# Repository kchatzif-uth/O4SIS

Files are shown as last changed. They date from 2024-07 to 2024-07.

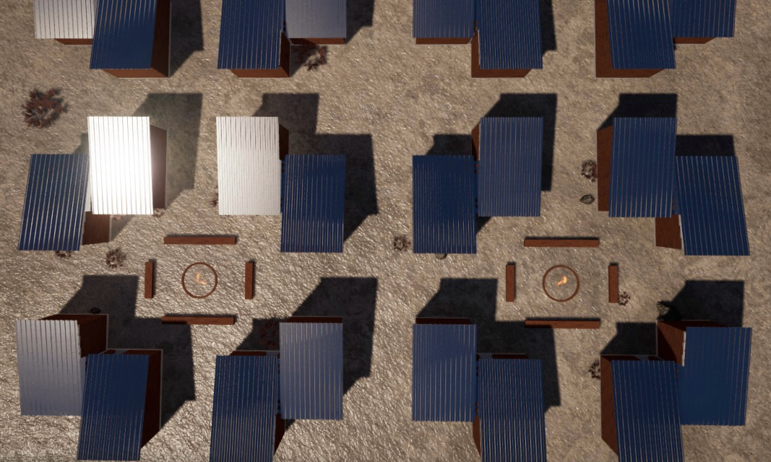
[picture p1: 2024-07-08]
ΦΩΤΟΡΕΑΛΙΣΤΙΚΑ/4.png

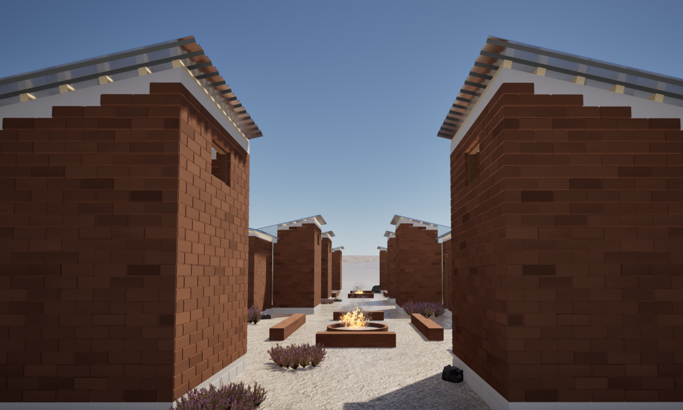
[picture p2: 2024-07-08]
ΦΩΤΟΡΕΑΛΙΣΤΙΚΑ/3.png

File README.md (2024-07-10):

Είμαστε μια ομάδα φοιτητριών του Πανεπιστήμιου Θεσσαλίας στο τμήμα Αρχιτεκτόνων Μηχανικών. Στο πλαίσιο του διδακτικού μαθήματος Ανοιχτός σχεδιασμός, κατασκευή και τεχνολογίες σχεδιάσαμε ένα πρωτότυπο καταφύγιο για πρόσφυγες. Η περιοχή εγκατάστασης του προτεινομένου καταυλισμού είναι η Υποσαχάρια Αφρική (Σαχέλ), συγκεκριμένα το Um Rakuba, Doka, του Σουδάν. Πρόκειται για μια μονάδα 20.75 τ.μ. ελάχιστης κατοίκισης, η οποία μπορεί να φιλοξενήσει έως 6 άτομα σε ανάγκη παρέχοντας 3.45τμ/άτομο. Το σχήμα της μονάδας αποτελείται από δυο παραλληλόγραμμα ίσου μεγέθους με κεκλιμένες οροφές αντίθετης κλίσης. Τα παραλληλόγραμμα απέχουν μεταξύ τους 0.2m και ενώνονται με 4 στήλες τούβλων και ένα ειδικό τεμάχιο. Το ένα τμήμα στεγάζει τον χώρο διαμονής με το υπνοδωμάτιο παρέχοντας τρείς κουκέτες ενώ το άλλο, τον χώρο διημέρευσης που αποτελείται από το μπάνιο και την κουζίνα. Το σχήμα έχει τέτοια δομή έτσι ώστε να πολλαπλασιάζεται σε 4αδες και να δημιουργούνται ανάμεσα χώροι συγκέντρωσης και συνάθροισης. Οι χώροι αυτοί λειτουργούν ως πλατείες, που στο κέντρο τους τοποθετείτε μία εστία που εξυπηρετεί στο μαγείρεμα και περιμετρικά υπάρχουν παγκάκια. Σκοπός, είναι η κατασκευή να ανταποκρίνεται στα κλιματολογικά και γεωγραφικά δεδομένα της επιλεγμένης περιοχής και η χρήση τοπικών υλικών. Έτσι με βάση μελέτης της περιοχής που επιλέχθηκε για την τοποθέτηση των καταλυμάτων, το Σουδάν, το μεγαλύτερο ποσοστό που αποτελεί τη μονάδα, τα τούβλα, παράγονται με χώμα, φλούδες ρυζιού και νερό. Κατά κύριο λόγω, η κατασκευή είναι ‘ανοιχτή’ τόσο σε σχεδιασμό όσο και σε κατασκευαστικό τομέα, καθώς όλα τα σχετικά δεδομένα που απαιτούνται για την δόμηση του καταλύματος βρίσκονται διαθέσιμα στην πλατφόρμα GITHUB. Τα δεδομένα αυτά προορίζονται για εθελοντές, οι οποίοι θα αναλάβουν πραγματοποίηση των καταφυγίων, στους οποίους θα απευθυνθούμε μέσω της της οργάνωσης UNHCR.

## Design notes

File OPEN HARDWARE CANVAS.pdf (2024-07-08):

ΤΟΥΒΛΑ x1804 (0,2m x 0,4m x 0,15m) ΛΑΜΑΡΙΝΕΣ x2 (3,2m x 4,7m) ΤΣΙΜΕΝΤΟΛΙΘΟΥΣ x62 (0,2m x 0,4m x 0,25m) ΞΥΛΙΝΑ ΔΟΚΑΡΙΑ x18 (0,1m x 0,1m x 2,9m) ΕΙΔΙΚΟ ΤΕΜΑΧΙΟ x1
ΥΔΡΟΡΡΟΕΣ x2 (d: 0,12m y: 3m)
ΞΥΛΙΝΕΣ ΚΑΣΕΣ ΠΑΡΑΘΥΡΟΥ x2 (0,8m x 0,6m x 0,1m)
ΞΥΛΙΝΗ ΚΑΣΑ ΠΟΡΤΑΣ x1 (0,8m x 2,25m x 0,1m) ΕΙΔΙΚΗ ΒΑΣΗ ΞΥΛΟΥ x36

Τοποθεσία:Um Rakuba, Doka, Σουδάν (ΣΑΧΕΛ) 20.75 m2 (3.45m2 / άτομο)
Καταφύγιο

Πρόσφυγες των γύρω περιοχών της Um Rakuba, Doka

.dwg (AUTOCAD)
.3dm (RHINO)
.pdf
.doc
.pptx
.mp4
.md

SOFTWARE:
Github
Autodesk

Υπολογιστής
Ίντερνετ
Υλικά -Εξοπλισμός κατασκευής: ΦΥΛΛΑΔΙΟ 01 (Github)
Open Design, Structures & Technologies | ΘΩΜΑ, ΧΑΤΖΗΦΩΤΙΑΔΟΥ, ΧΡΙΣΤΟΦΙΛΟΥ
- https://www.researchgate.net/figure/Spacers-used-to-preventcompressing-the-insulation_fig5_348600514 (https://www.researchgate.net/figure/Spacers-used-to-prevent-compressing-the-insulation_fig5_348600514)
- https://www.dezeen.com/2019/09/17/cortex-shelter-cutworkrefugee-architecture/ (https://www.dezeen.com/2019/09/17/cortex-shelter-cutwork-refugee-architecture/)
- https://www.designboom.com/architecture/shigeru-ban-kalobeyeirefugee-shelters-turkana-kenya-philippe-monteil-un-habitat-unhcr-03-07-2022/ (https://www.designboom.com/architecture/shigeru-ban-kalobeyei-refugee-shelters-turkana-kenya-philippe-monteil-un-habitat-unhcr-03-07-2022/)
- https://perunanuovacasaitaliana.wordpress.com/2016/04/15/architects-for-society-designs-low-cost-hexagonal-shelters-for-refugees/ (https://perunanuovacasaitaliana.wordpress.com/2016/04/15/architects-for-society-designs-low-cost-hexagonal-shelters-for-refugees/)

Ομάδα εθελοντών με εξοικείωση στον κατασκευαστικό τομέα

Θα συνεργαστούμε με την οργάνωση UNHCR μέσω της οποίας θα βρεθεί η κατάλληλη ομάδα εθελοντών για την κατασκευή του καταυλισμού

# O 4 S I S

Οδηγίες (Github):
1. ΦΥΛΛΑΔΙΟ 01: https://github.com/kchatzifuth/O4SIS/blob/main/%CE%A6%CE%A5%CE%9B%CE %9B%CE%91%CE%94%CE%99%CE%9F%2001.pdf
2. ΦΥΛΛΑΔΙΟ 02: https://github.com/kchatzifuth/O4SIS/blob/main/%CE%A6%CE%A5%CE%9B%CE %9B%CE%91%CE%94%CE%99%CE%9F%2002.pdf

Θα απευθυνθούμε στηνοργάνωση UNHCR μέσω της οποίας θα βρεθούν τα άτομα σε ανάγκη

Δεν χρειάζεται κάποιο είδος οδηγίας προκυμμένου να χρησιμοποιηθεί η συγκεκριμένη δομή.

Software:
- AUTOCAD
- ADOBE SYSTEMS

Οδηγίες στο Github:
- ΦΥΛΛΑΔΙΟ 01
- ΦΥΛΛΑΔΙΟ 02
- GIF

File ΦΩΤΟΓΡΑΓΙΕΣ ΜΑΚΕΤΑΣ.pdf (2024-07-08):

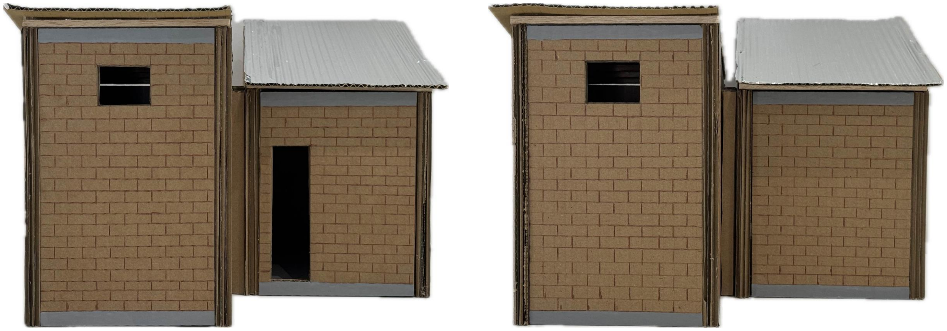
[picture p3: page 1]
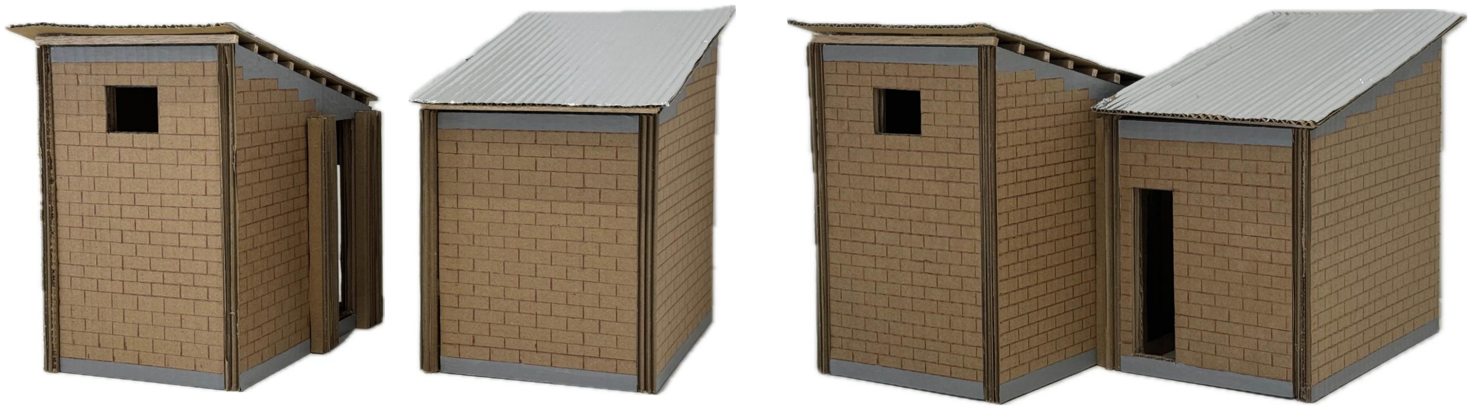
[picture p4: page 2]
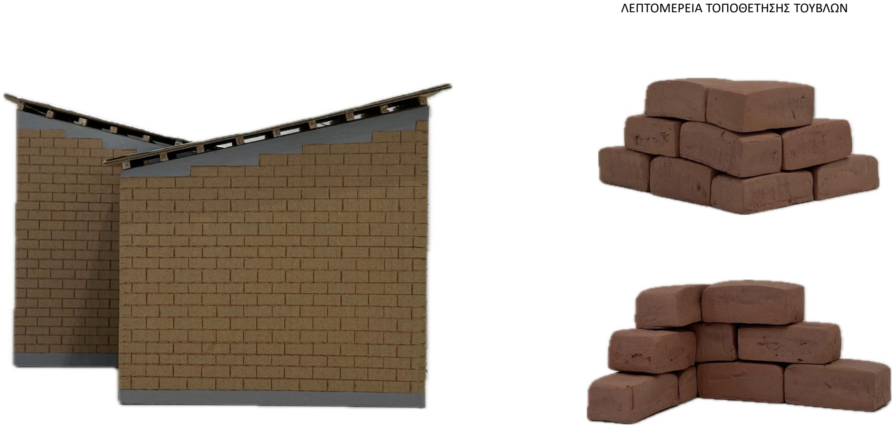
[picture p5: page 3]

ΛΕΠΤΟΜΕΡΕΙΑ ΤΟΠΟΘΕΤΗΣΗΣ ΤΟΥΒΛΩΝ

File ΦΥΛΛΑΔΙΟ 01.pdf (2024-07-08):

### ΦΥΛΛΑΔΙΟ 01: ΟΔΗΓΙΕΣ ΚΑΤΑΣΚΕΥΗΣ

ΥΛΙΚΑ

ΕΞΟΠΛΙΣΜΟΣ

ΤΟΥΒΛΑ x1804 (0,2m x 0,4m x 0,15m) ΛΑΜΑΡΙΝΕΣ x2 (3,2m x 4,7m) ΤΣΙΜΕΝΤΟΛΙΘΟΥΣ x62 (0,2m x 0,4m x 0,25m) ΞΥΛΙΝΑ ΔΟΚΑΡΙΑ x18 (0,1m x 0,1m x 2,9m)
ΕΙΔΙΚΟ ΤΕΜΑΧΙΟ x1
ΥΔΡΟΡΡΟΕΣ x2 (d: 0,12m y: 3m)
ΞΥΛΙΝΕΣ ΚΑΣΕΣ ΠΑΡΑΘΥΡΟΥ x2 (0,8m x 0,6m x 0,1m) ΞΥΛΙΝΗ ΚΑΣΑ ΠΟΡΤΑΣ x1 (0,8m x 2,25m x 0,1m) ΕΙΔΙΚΗ ΒΑΣΗ ΞΥΛΟΥ x36
ΒΙΔΕΣ ΞΥΛΟΥ x216
ΒΙΔΕΣ ΓΙΑ ΛΑΜΑΡΙΝΑ x36
ΕΠΙΚΑΛΥΠΤΡΑ x36
ΜΠΕΤΟ

ΚΑΛΟΥΠΙ ΤΟΥΒΛΩΝ
ΜΕΤΡΟ
ΦΤΥΑΡΙ
ΚΡΟΥΣΤΙΚΟ ΤΡΥΠΑΝΙ
ΓΑΝΤΙΑ
ΚΑΤΣΑΒΙΔΙ
ΓΑΛΛΙΚΟ ΚΛΕΙΔΙ

Βήμα 1:
Συγκεντρώνουμε τα υλικά (χώμα, νερό, φλούδες ρυζιού).
Αναμειγνύουμε το χώμα με το νερό και έπειτα προσθέτουμε τις φλούδες ρυζιού έως ότου να ομογενοποιηθούν.

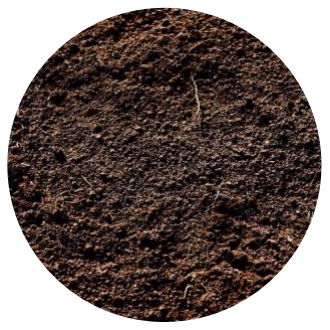
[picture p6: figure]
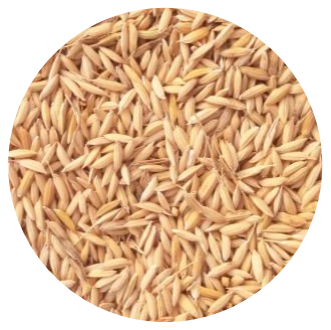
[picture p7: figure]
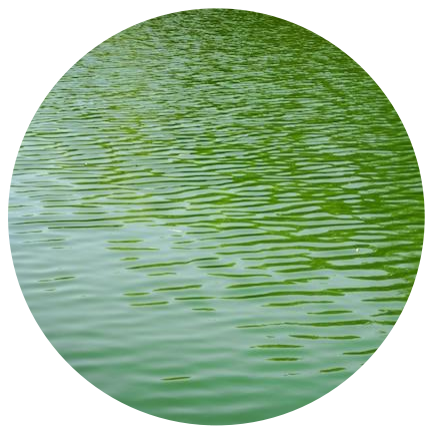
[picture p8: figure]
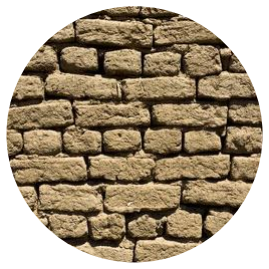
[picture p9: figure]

Εικ.1. Χώμα | Εικ.2. Φλούδες ρυζιού | Εικ.3. Νερό | Εικ.4. Τούβλα Λάσπης

Βήμα 2:
Γεμίζουμε το κάθε καλούπι με το χώμα, το ξεφορμάρουμε και το αφήνουμε στον ήλιο για 10 μέρες για να σταθεροποιηθούν. Σχηματίζουμε τούβλα 20x40x15 cm. Επαναλαμβάνουμε την ιδιά διαδικασία για όσες φορές χρειαστεί.

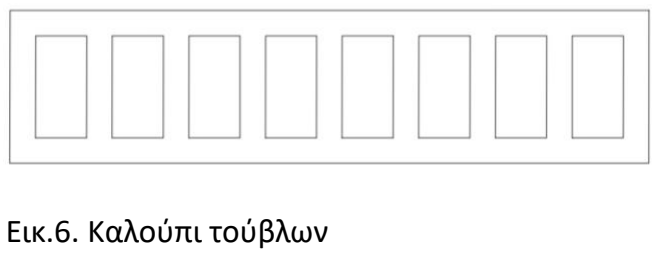
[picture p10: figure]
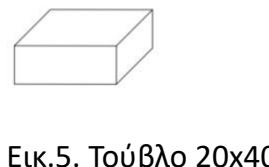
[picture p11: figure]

Εικ.5. Τούβλο 20x40x15 cm | Εικ.6. Καλούπι τούβλων

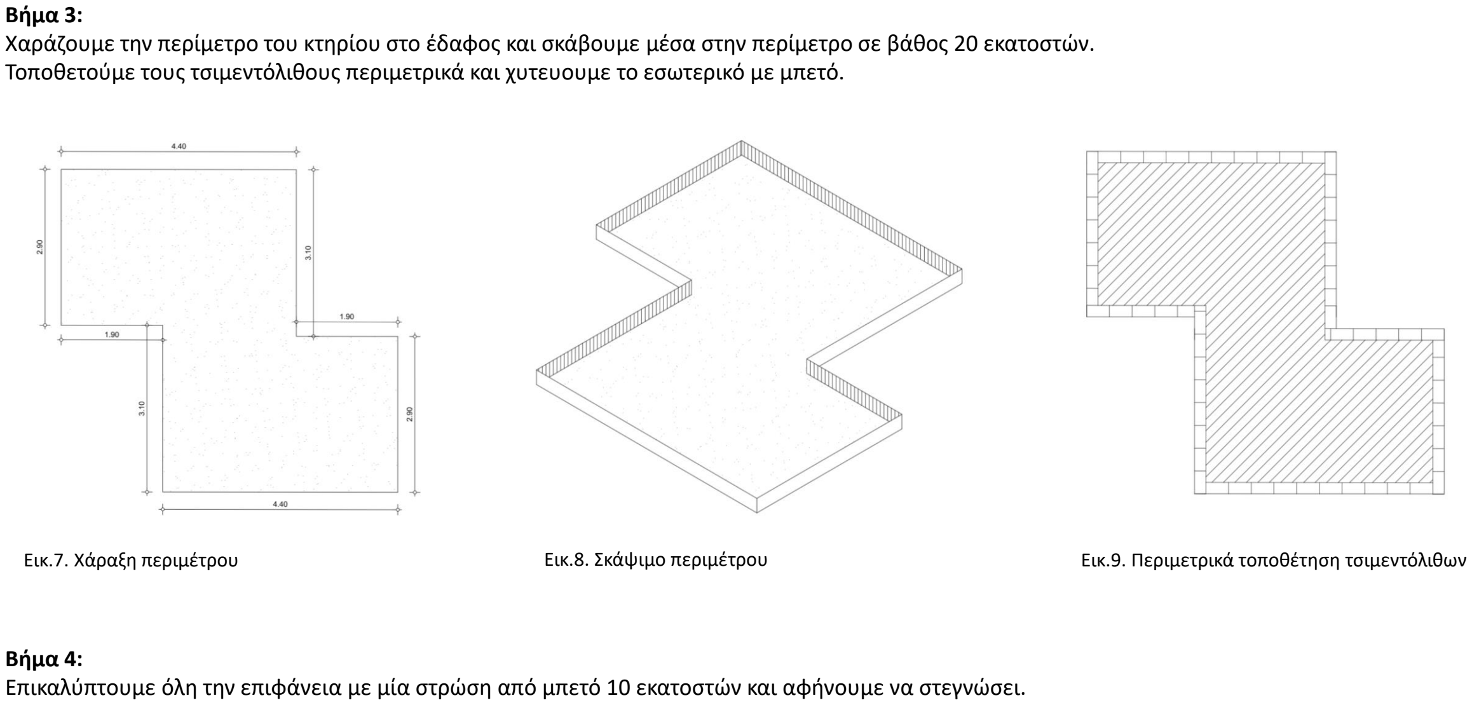
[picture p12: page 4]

Βήμα 3:
Χαράζουμε την περίμετρο του κτηρίου στο έδαφος και σκάβουμε μέσα στην περίμετρο σε βάθος 20 εκατοστών. Τοποθετούμε τους τσιμεντόλιθους περιμετρικά και χυτευουμε το εσωτερικό με μπετό.

Βήμα 4:
Επικαλύπτουμε όλη την επιφάνεια με μία στρώση από μπετό 10 εκατοστών και αφήνουμε να στεγνώσει.
Εικ.7. Χάραξη περιμέτρου | Εικ.8. Σκάψιμο περιμέτρου | Εικ.9. Περιμετρικά τοποθέτηση τσιμεντόλιθων

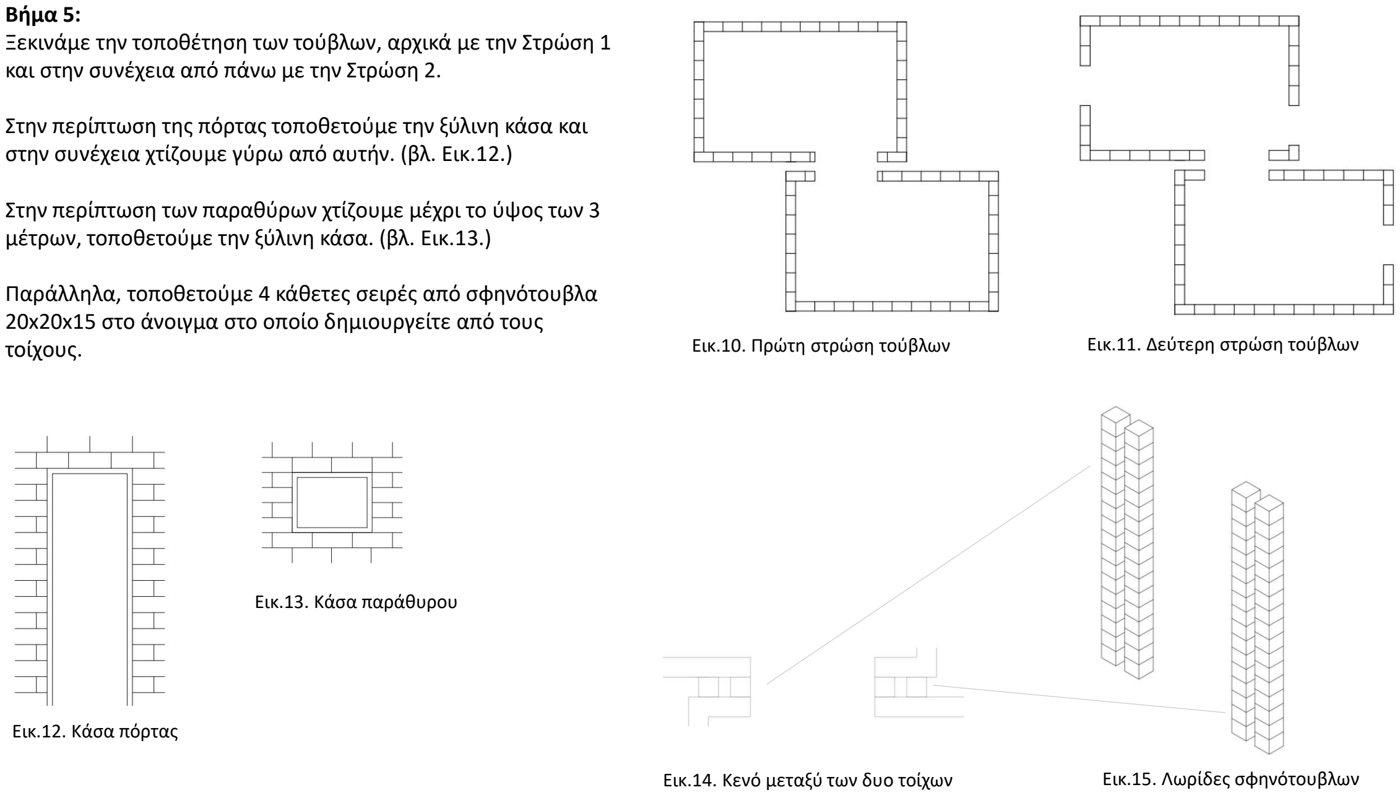
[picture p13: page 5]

Βήμα 5:
Ξεκινάμε την τοποθέτηση των τούβλων, αρχικά με την Στρώση 1 και στην συνέχεια από πάνω με την Στρώση 2.

Στην περίπτωση της πόρτας τοποθετούμε την ξύλινη κάσα και στην συνέχεια χτίζουμε γύρω από αυτήν. (βλ. Εικ.12.)

Στην περίπτωση των παραθύρων χτίζουμε μέχρι το ύψος των 3 μέτρων, τοποθετούμε την ξύλινη κάσα. (βλ. Εικ.13.)

Παράλληλα, τοποθετούμε 4 κάθετες σειρές από σφηνότουβλα
20x20x15 στο άνοιγμα στο οποίο δημιουργείτε από τους
τοίχους. | Εικ.10. Πρώτη στρώση τούβλων | Εικ.11. Δεύτερη στρώση τούβλων

Εικ.13. Κάσα παράθυρου

Εικ.12. Κάσα πόρτας

Εικ.14. Κενό μεταξύ των δυο τοίχων | Εικ.15. Λωρίδες σφηνότουβλων

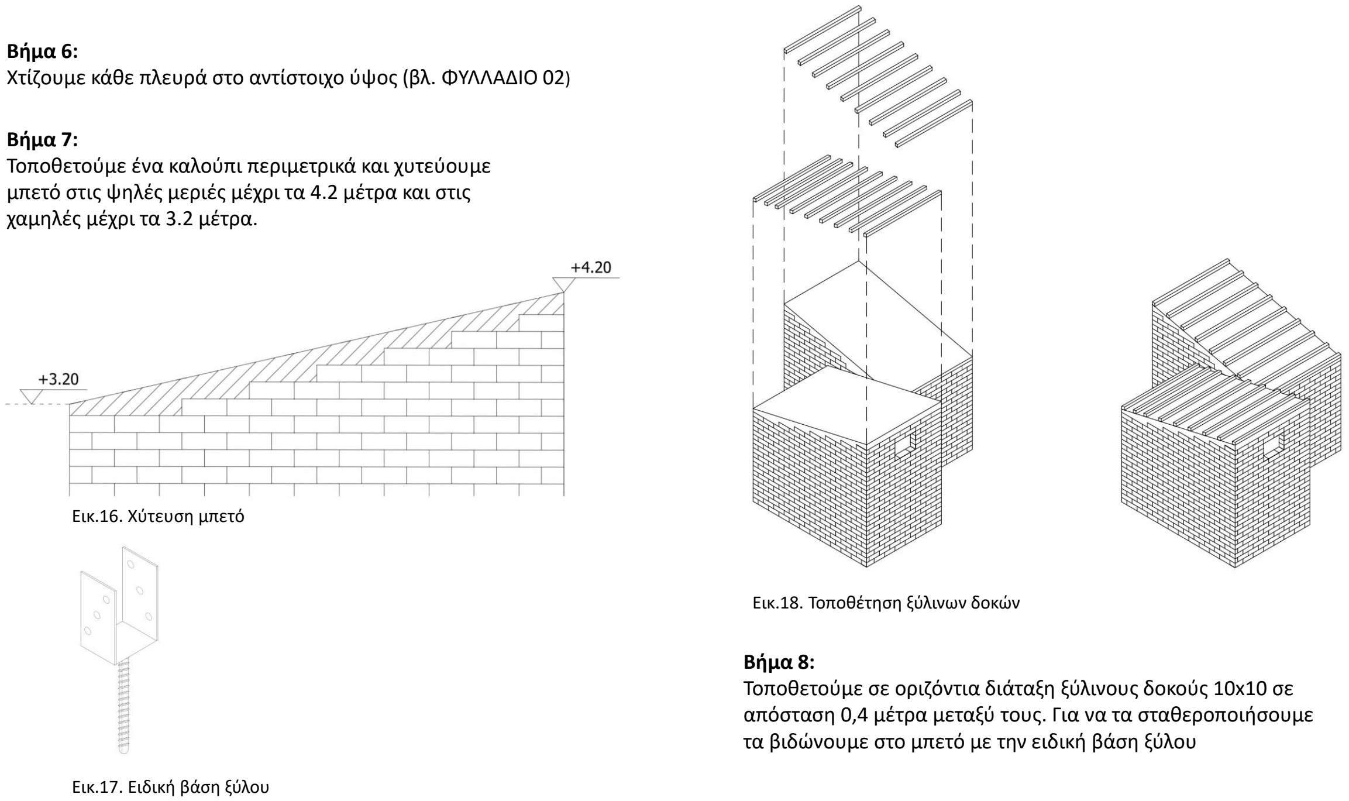
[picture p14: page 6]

Βήμα 6:
Χτίζουμε κάθε πλευρά στο αντίστοιχο ύψος (βλ. ΦΥΛΛΑΔΙΟ 02)

Βήμα 7:
Τοποθετούμε ένα καλούπι περιμετρικά και χυτεύουμε
μπετό στις ψηλές μεριές μέχρι τα 4.2 μέτρα και στις χαμηλές μέχρι τα 3.2 μέτρα.

Βήμα 8:
Τοποθετούμε σε οριζόντια διάταξη ξύλινους δοκούς 10x10 σε απόσταση 0,4 μέτρα μεταξύ τους. Για να τα σταθεροποιήσουμε τα βιδώνουμε στο μπετό με την ειδική βάση ξύλου

Εικ.16. Χύτευση μπετό

Εικ.18. Τοποθέτηση ξύλινων δοκών

Εικ.17. Ειδική βάση ξύλου

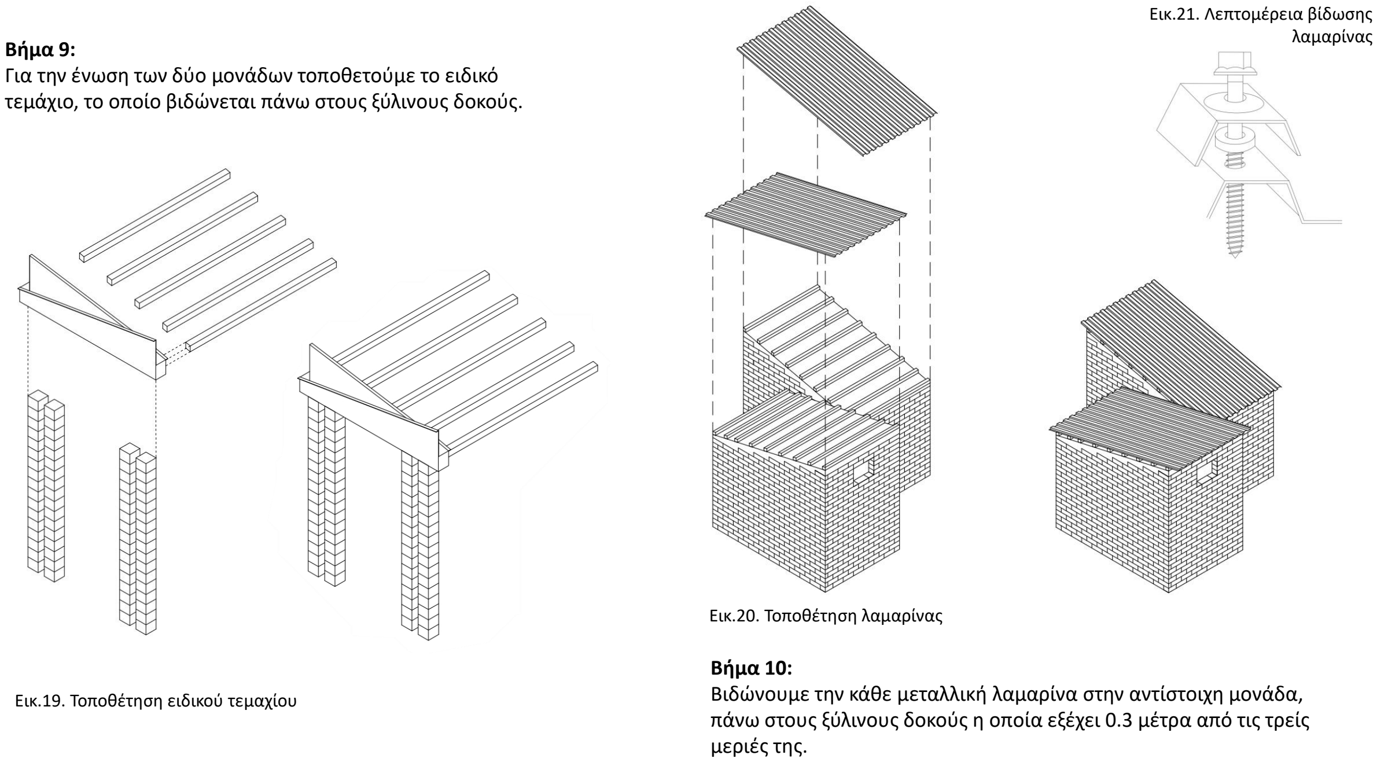
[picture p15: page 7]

Βήμα 9:
Για την ένωση των δύο μονάδων τοποθετούμε το ειδικό τεμάχιο, το οποίο βιδώνεται πάνω στους ξύλινους δοκούς.

Βήμα 10:
Βιδώνουμε την κάθε μεταλλική λαμαρίνα στην αντίστοιχη μονάδα, πάνω στους ξύλινους δοκούς η οποία εξέχει 0.3 μέτρα από τις τρείς μεριές της.

Εικ.19. Τοποθέτηση ειδικού τεμαχίου

Εικ.20. Τοποθέτηση λαμαρίνας

Εικ.21. Λεπτομέρεια βίδωσης λαμαρίνας

Βήμα 11:
Συνδέουμε τις δύο υδρορροές, μία σε κάθε πλευρά, με το ειδικό τεμάχιο και τις κάθετες σειρές των τούβλων.

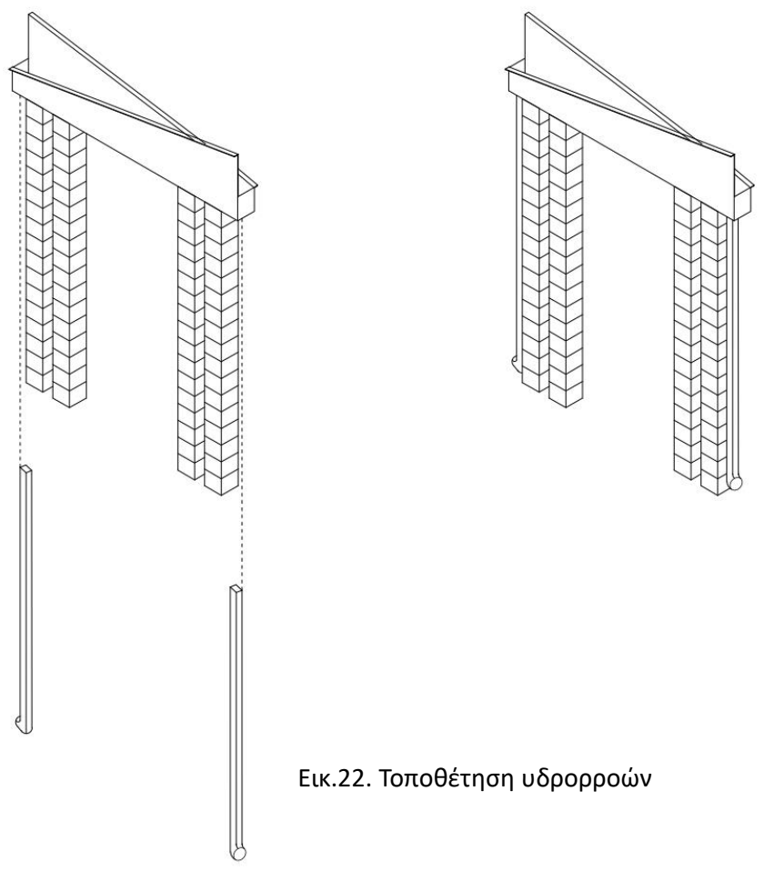
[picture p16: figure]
Εικ.22. Τοποθέτηση υδρορροών

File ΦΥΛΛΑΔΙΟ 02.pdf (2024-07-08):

## ΦΥΛΛΑΔΙΟ 02: ΥΨΗ

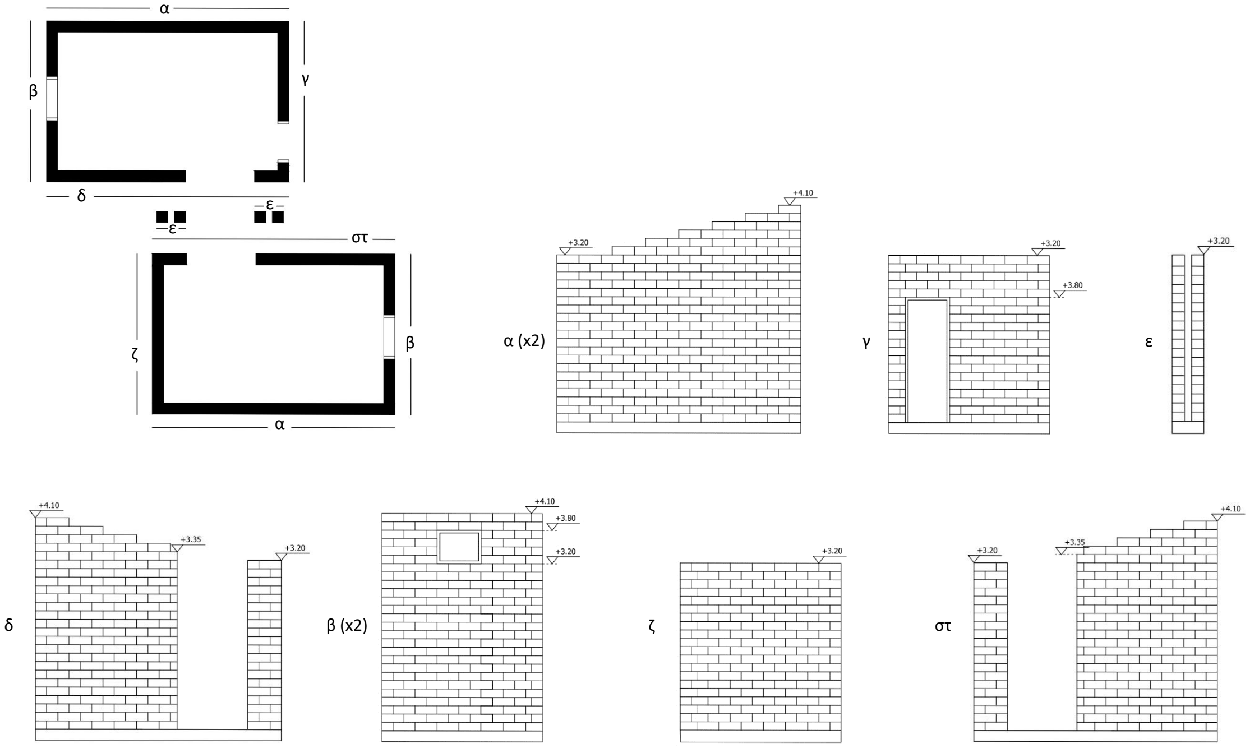
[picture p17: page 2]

α (x2

)

δ | β (x2

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
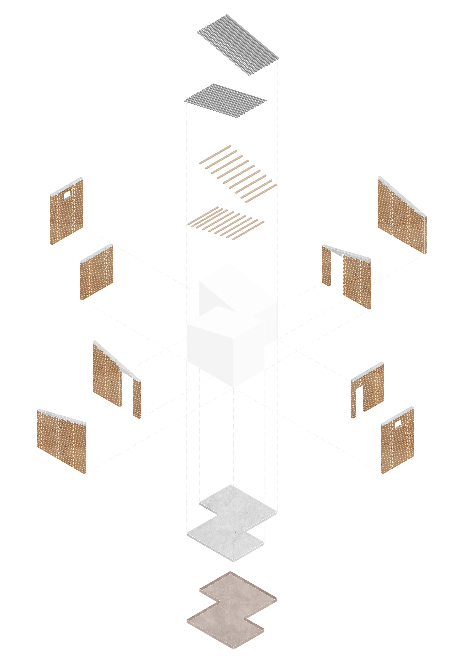
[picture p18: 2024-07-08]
RENDER ΑΞΟΝΟΜΕΤΡΙΚΟ ΣΕ ΕΚΡΗΞΗ.jpg

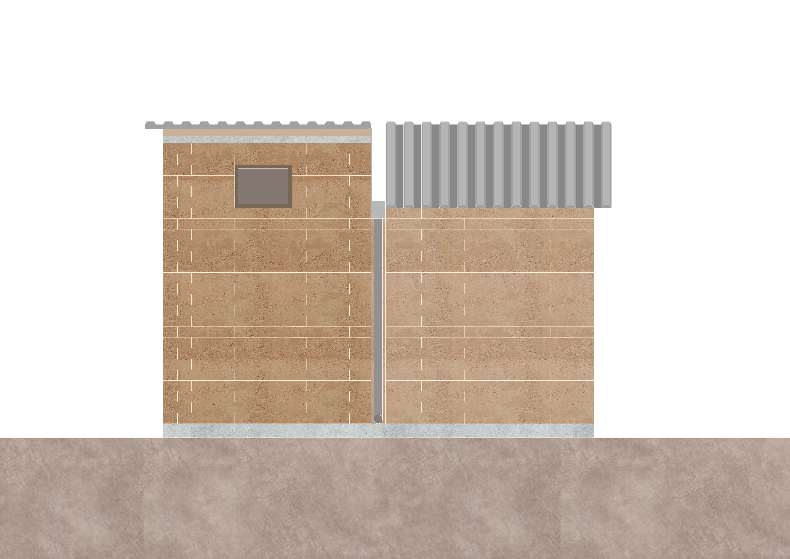
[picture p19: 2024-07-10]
ΣΧΕΔΙΑ (RENDER)/ΟΨΗ β.jpg

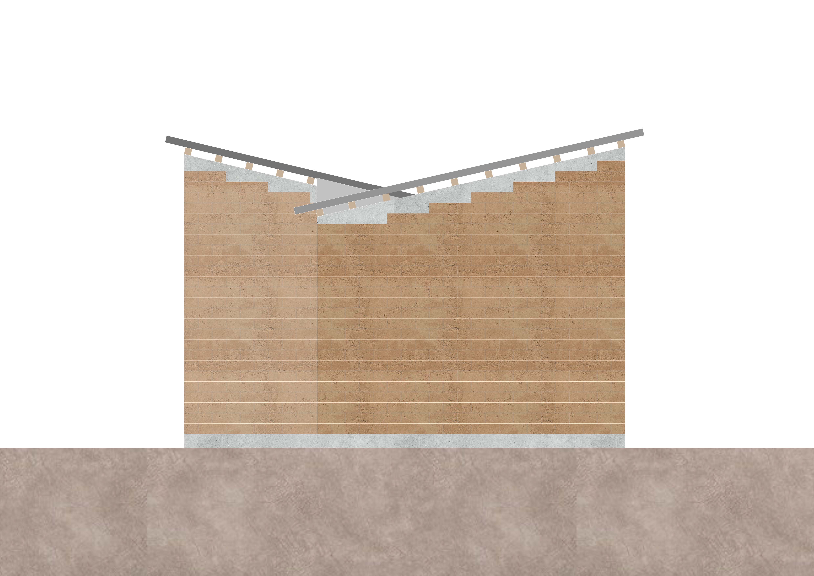
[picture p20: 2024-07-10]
ΣΧΕΔΙΑ (RENDER)/ΟΨΗ α & α'.jpg

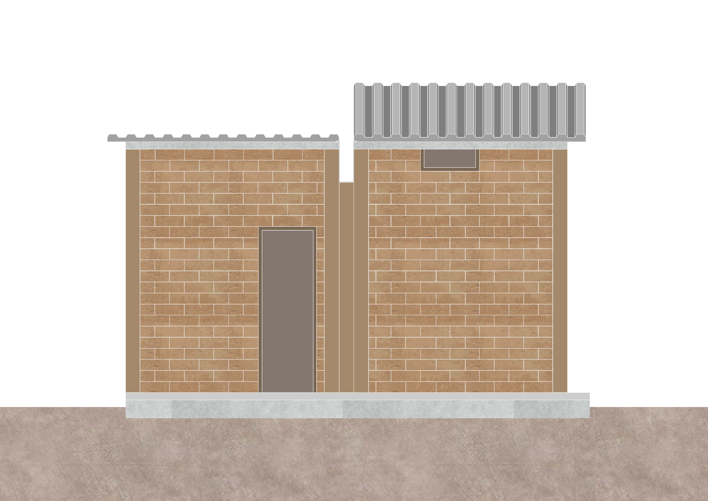
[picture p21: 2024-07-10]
ΣΧΕΔΙΑ (RENDER)/ΤΟΜΗ Α-Α'.jpg

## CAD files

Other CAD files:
ΣΧΕΔΙΑ.dwg

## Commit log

2024-07-08 O4SIS
    Είμαστε μια ομάδα φοιτητριών Αρχιτεκτονικής του Πανεπιστήμιου Θεσσαλίας στο τμήμα Αρχιτεκτόνων Μηχανικών. Στο πλαίσιο του διδακτικού μαθήματος Ανοιχτός σχεδιασμός, κατασκευή και τεχνολογίες σχεδιάσαμ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
2024-07-08 ΠΕΡΙΓΡΑΦΗ.md
